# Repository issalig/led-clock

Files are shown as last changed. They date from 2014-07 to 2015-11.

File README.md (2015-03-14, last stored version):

led-clock
=========

Clock adventures with a led matrix.

After thinking about the simplest way to build a word clock I experimented with hand-soldered led matrices, 74HC595, 7219 and others to end up with the mighty 7219 and 8x8 led matrices.

7219 works with common cathode displays but a nice workaround to make it work with common anode matrices is to interchange rows by cols (transposing the matrix) and do the same (transposing it again) from software. Anyway, the PCB has been designed to support both c.c. and c.a. as well as 3mm matrices.

In order to make it richer, led-clock supports a humidity sensor and a pressure sensor. Additional sensors are also supported via I2C or SPI.

Hardware list
-------------

  - Arduino Pro Mini
  - Max7219
  - Led matrix 8x8 5mm/3mm common cathode or anode
  - Humidity sensor DHT11
  - Pressure sensor BMP180
  - 2 buttons

Board features
--------------

  - Small factor 5cmx5cm (fits in cheap PCB manufacturing)
  - Exported I2C, SPI and Analog pins
  - Stackable (1 or more matrices)
  - Support for common cathode and common anode

Software
--------

  Arduino has been chosen as the development environment due to the available libraries and its simplicity. MSP430 has been also considered but I was not able to make it work. Any volunteer?

  Operation modes:
  -Sleep. Wake up when button is touched
  -Alarm.

Clock layout
------------

  The idea is to have different interchangeable covers allowing the clock to easily change its appearance (and behaviour).
  By default two types of clock are designed:
  
- word clock
      Consists of a grid of characters that contain the words for telling the time in natural language.
      
- number/symbol clock
      Consists of a grid with digits and some extra symbols to indicate weather, moon, etc, ...
      
- calendar
	  Consists of a grid with days of week, month, weather, ... (mark first of month to calculate number of day)
	  
- anyclock
    Feel free to design your own clock, just represent your info in 64 elements (or more)

TODO
----
  - Checklist
	- 3.3v and 5v on board
		(boost for 5v even with batt)
		(3.3v with logic level or dedicated?)
		http://lowpowerlab.com/blog/2014/03/13/moteino-power-shield-now-available/
    - Lipo battery or 3xAAA???
	- Boost??
	- Jumper for A or K
	- datain for 5219 on not pwm??
	- 2 button
		1 is mode: sleep, set hour, 
		1 is set:  +1, next option
	- 3 button	
    - buzzer connection  //1M resistor ??? just servo/generic connector (-+S)
	- remote connection // risk, interference with voltage, just connector(-+S)
	- xronos clock (how they manage buttons, eeprom)
  - Wishlist

  - New PCB for 1st 1/4 2015 (SMD)
    - (OK) Correct GND mask from previous version 0.3
    - (OK) Remove DS1307 circuitry and substitute it for a module
	- (OK) Nokia screen
    - (OK) Correct button footprint holes
	- (OK) Documentation for pinout
	- (OK) Support for radio TEA5767
	- (OK) Possibility of adding capes
    - (OK) Pinout assignment and reserved pins
	- (OK) Pass also I2C, SPI pins on stackable horizontal	
	- (OK) Remote IR 1838
	
  - Software  
    - Grid data structure for symbols    
    - Grid editor (http://jsfiddle.net/AAg8e/4/)
    
  - Case
    - Carboard, bands and needles. Easy to change front mask cover
    - Wood. (Anyone with a laser cutter/CNC?)
 
 - Masks
	- word, temperature, humidex, calendar, spectrum analyzer
	- rotating wheel and servo?
 - Capes
	- stackable capes: nokia screen, communication, motor, radio TEA5767 / TDA7330 ...

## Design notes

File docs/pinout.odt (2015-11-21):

Pin | Function | Phys Posit | Board2 | Board 3 | Board 4 | Exp | Notes
A0 | | | B | | DataIn7219 | x
A1 | | | B | | IR1838!! | x | Battery?
A2 | | | B | | LDR | x
A3 | | | B | | DHT11 | x
A4 | SDA (I2C) | Variable | | Baro,RTC | Baro,RTC,TEA | x
A5 | SCL (I2C) | Variable | | Baro,RTC | Baro,RTC,TEA | x
A6 | | Variable | | NC | NC | | Button3?
A7 | | Variable | | NC | NC
D0 | RX | | | | | x | Comm
D1 | TX | | | | | x | Comm
D2 | | | | Button0 | Button0
D3 | PWM | | | Button1 | RGB/R | x | RGB/Servo0
D4 | | | | Button2 | Button1
D5 | PWM | | | Button3 | RGB/G | x | RGB/Servo1
D6 | PWM | | | DHT11 | RGB/B | x | RGB/Servo2
D7 | | | | load7219 | Load7219/ rstnokia-1/SD_CS
D8 | | | | clk7219 | Clk7219/ dcnokia-3/TFT_DC
D9 | PWM | | | dataIn7219 | dataIn7219/ lightnokia-7/TFT_RST | x | Change to Analog pin?
D10 | SS (SPI) PWM | | 7219 | | Cenokia-2/CS_TFT | x
D11 | MOSI (SPI) PWM | | 7219 | | DINNokia-4/TFT_SDA-SD_MOSI | x
D12 | MISO (SPI) | | 7219 | | SD_MISO | x
D13 | SCK (SPI) LED | | | | SCKNokia-5 / SD_SCK TFT_SCK | x

Quality control 0,4

rgb OK, queda azul ??? comparte con dht11 por D6

tft inverted!!!!

nokia, sin resistencias en sck sda, transistor mal patillaje, jumper para setear luz?

rtc

radio, no está ruteado a4SCL a5sda I2C !!!

ir

ldr

bmp ok

dht ok está en el 6 y debería ser 3, colapsa con RGB (B)

7219 Anode OK

check resistejcias nokia, funciona script

servos, mal pinout, colapsan con boton, soldar machos en placa

cambiar pinout antena a la derecha y dejar masa en medio LR

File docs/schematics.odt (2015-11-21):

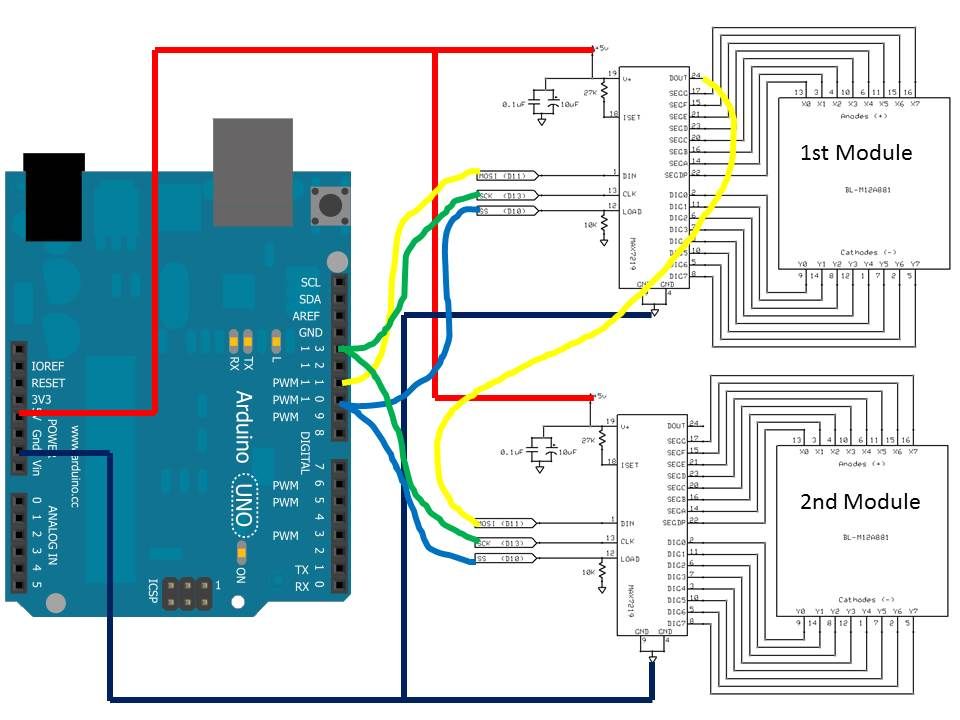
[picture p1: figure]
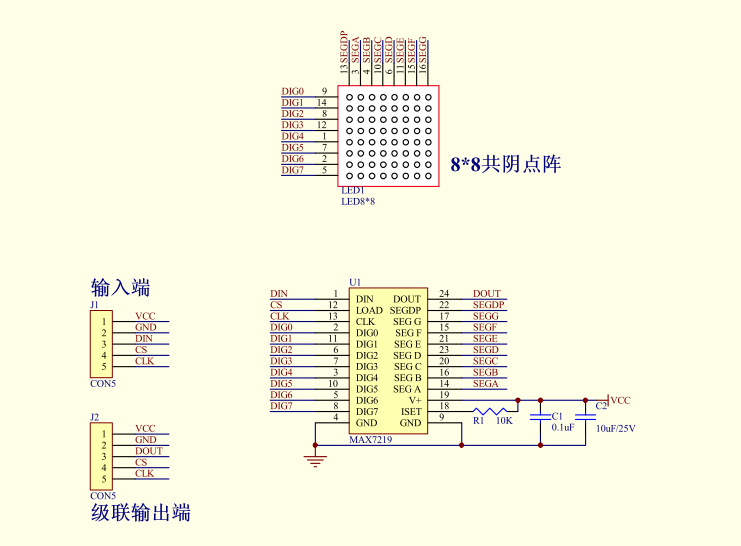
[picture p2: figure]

UVp-2088 Column Anode → Common cathode in row

Row Cathode

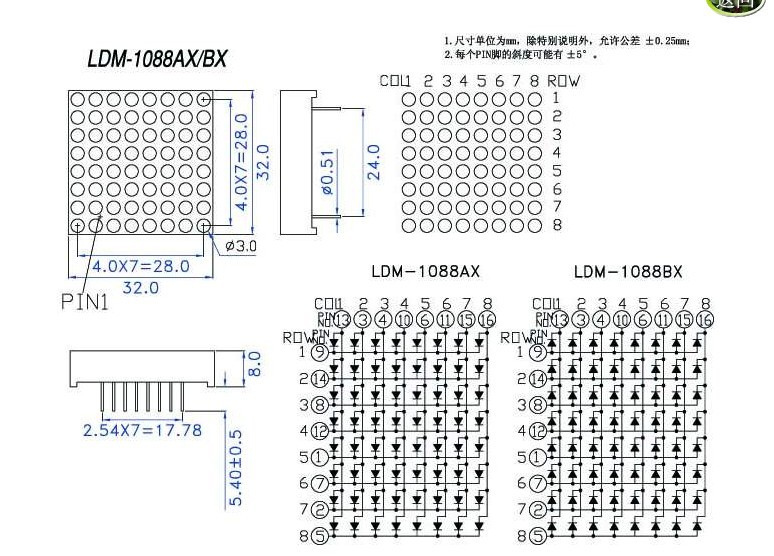
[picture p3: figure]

(http://i0.wp.com/tronixstuff.com/wp-content/uploads/2013/09/max7219_resistor_table.jpg)

(http://i0.wp.com/tronixstuff.com/wp-content/uploads/2013/09/max7219_resistor_table.jpg)

http://i0.wp.com/tronixstuff.com/wp-content/uploads/2013/09/max7219_resistor_table.jpg

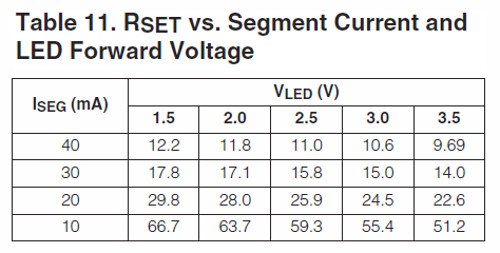
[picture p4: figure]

http://www.planetarduino.org/?cat=432

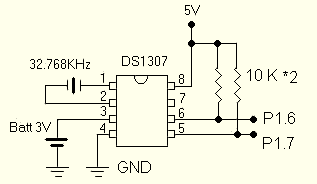
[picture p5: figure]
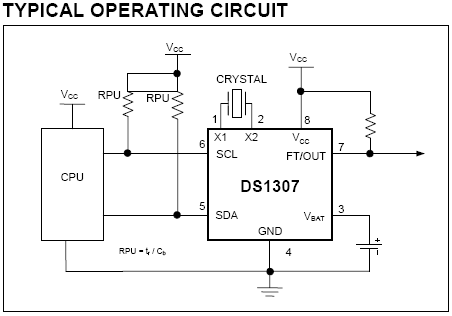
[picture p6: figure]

conect rtc to arduino.

conect SDA to Arduino A4.
conect SCL to Arduino A5.
conect vcc to +5v
conect gnd to gnd

http://www.instructables.com/id/Clock-with-termometer-using-Arduino-i2c-16x2-lcd-D/

http://www.sharatronica.com/cd4017.html

Sensor óptico

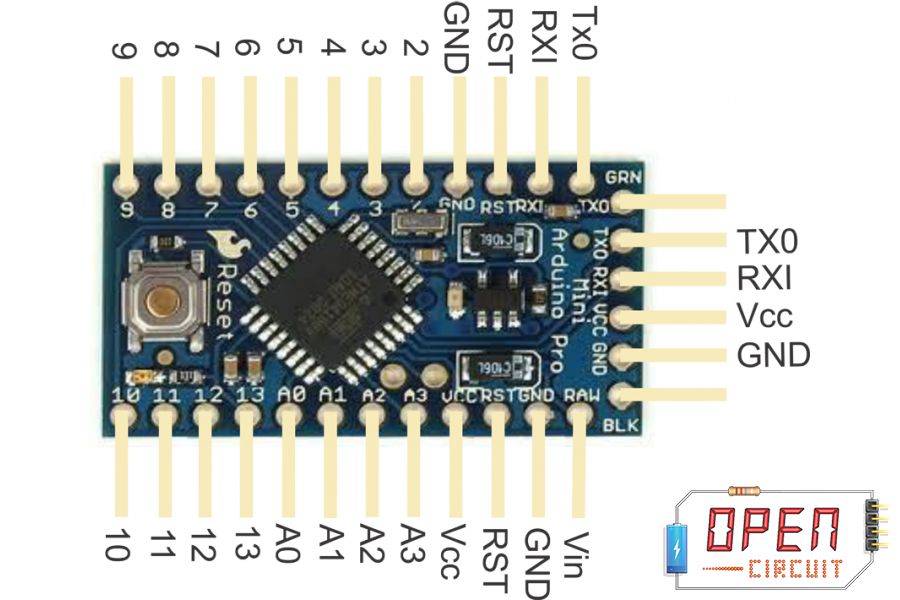
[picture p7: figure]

http://www.hobbytronics.co.uk/mosfet-voltage-level-converter

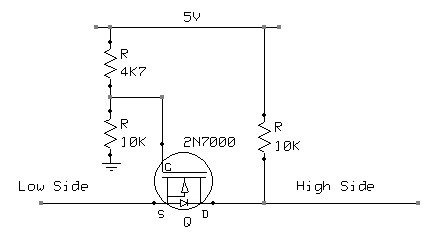
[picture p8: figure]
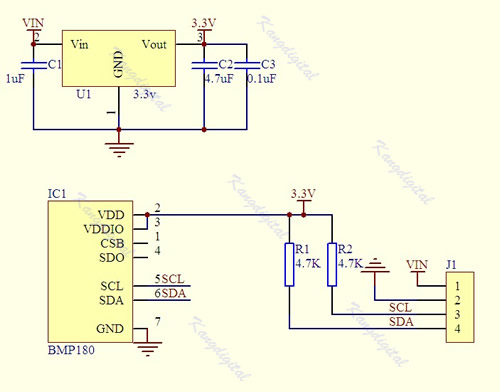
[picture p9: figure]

Placa

Main board

En v0.2 están A0, A1, A2, A3 para botones (en placa A0, A1, A2, A3)

El chip usa los pines 10, 11, 12

Se exportan 2-9 (en placa D2-D9)

13 libre

Botones → En v.0.1 K4 es A0, K3 es A1. http://arduino.cc/en/Tutorial/InputPullupSerial

pinMode(0, INPUT_PULLUP); analogRead(0); (se han cableado a analog)???

TODO

Arreglar conexión masas en V.0.3 para V.0.4. OK

Revisar agujeros batería, demasiado grandes. ELIMINAR

Revisar agujeros switch, demasiado pequeños. OK

Añadir TEA5767 / TDA7330 http://www.vwlowen.co.uk/arduino/bedside-clock/page2.htm

http://nicuflorica.blogspot.ro/2013/06/radio-fm-cu-tea5767-si-arduino-ii.html

http://blog.simtronyx.de/en/simple-fm-stereo-radio-with-a-tea5767-breakout-module-and-an-arduino/

http://nicuflorica.blogspot.ro/2014/11/modul-de-afisare-cu-8-cifre-led-din-7_11.html

Sensor-power

RTC se conecta por I2C SDA (A4) SCL (A5)

Scanning...

I2C device found at address 0x50 ! MEM

I2C device found at address 0x68 ! RTC

done

BMP180 SDA (A4) SCL (A5) (OK)

DHT11 conecta a D6 (OK)

BOOST (pendiente)

Es posible usar otros con SerialTWI

SPI: 10 (SS), 11 (MOSI), 12 (MISO), 13 (SCK).

Poner también batería?

Cargador? 2 AA

In addition, some pins have specialized functions:

- Serial: 0 (RX) and 1 (TX). Used to receive (RX) and transmit (TX) TTL serial data. These pins are connected to the TX-0 and RX-1 pins of the six pin header.
- External Interrupts: 2 and 3. These pins can be configured to trigger an interrupt on a low value, a rising or falling edge, or a change in value. See the attachInterrupt() (http://arduino.cc/en/Reference/AttachInterrupt) function for details.
- PWM: 3, 5, 6, 9, 10, and 11. Provide 8-bit PWM output with the analogWrite() (http://arduino.cc/en/Reference/AnalogWrite) function.
- SPI: 10 (SS), 11 (MOSI), 12 (MISO), 13 (SCK). These pins support SPI communication, which, although provided by the underlying hardware, is not currently included in the Arduino language.
- LED: 13. There is a built-in LED connected to digital pin 13. When the pin is HIGH value, the LED is on, when the pin is LOW, it's off.

The Pro Mini has 8 analog inputs, each of which provide 10 bits of resolution (i.e. 1024 different values). Four of them are on the headers on the edge of the board; two (inputs 4 and 5) on holes in the interior of the board. The analog inputs measure from ground to VCC. Additionally, some pins have specialized functionality:

- I²C: A4 (SDA) and A5 (SCL). Support I²C (TWI) communication using the Wire library (http://arduino.cc/en/Reference/Wire).

There is another pin on the board:

- Reset. Bring this line LOW to reset the microcontroller. Typically used to add a reset button to shields which block the one on the board.

# Protel Gerber Layer Names

GTO - Gerber Top Overlay (silkscreen)

GBO - Gerber Bottom Overlay (silkscreen)

GTL - Gerber Top Signal

GBL - Gerber Bottom Signal

GTS - Gerber Top Solder Mask

GBS - Gerber Bottom Solder Mask

GTP - Gerber Top Paste Mask

GBP - Gerber Bottom Paste Mask

GM1 - Gerber Mechanical 1

GM2 - Gerber Mechanical 2

GM3 - Gerber Mechanical 3

GM4 - Gerber Mechanical 4

GDD - Gerber Drill Drawing

GD1 - Gerber Drill Drawing, Top To Mid 1

GD2 - Gerber Drill Drawing, Mid 1 To Mid 2

GDG - Gerber Drill Guide

GG1 - Gerber Drill Guide, Top To Mid 1

GG2 - Gerber Drill Guide, Mid 1 To Mid 2

GPT - Gerber Top Pad Master

GPB - Gerber Bottom Pad Master

GKO - Gerber Keepout

PO1 - Gerber Panels

REP - Report file

TXT - ASCII NC Drill

DRL - EIA NC Drill

DRR - NC Drill Report

APR - Aperature File

Kicad, Plot, Drill . Kicad2itead.bat

2. Gerber files needed for 2-layer & 4-layer PCB boards:

Top layer: pcbname.GTL

Bottom layer: pcbname.GBL

Solder Stop Mask top: pcbname.GTS

Solder Stop Mask Bottom: pcbname.GBS

Silk Top: pcbname.GTO

Silk Bottom: pcbname.GBO

NC Drill: pcbname.TXT

Outline layer: pcbname.GKO or pcbname.DO

Note:

- All the gerber files must be in RS-274x format, except the drill file should be in Excellon format.
- If there is no pcbname.GKO or DO file, please make sure the PCB outline or shape shall at least be specified in other layer, silkscreen or soldermask layer etc.
- If soldermask layers are not required, please clarify surface finish for both sides when you submit your gerber files.

Coin cell holder

http://www.shogyo.com/pdf/ch224-2032lf.pdf

NOKIA LCD takes 4 digital lines

3.3V !!!

http://www.google.es/url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,d.d24&psig=AFQjCNFrW_TDc2UuTrOCLbg6gxJRcV6MJQ&ust=1420762184205945

http://drianoxaman.blogspot.com.es/2013/03/arduino-usb-lipo-charger-5v-booster.html

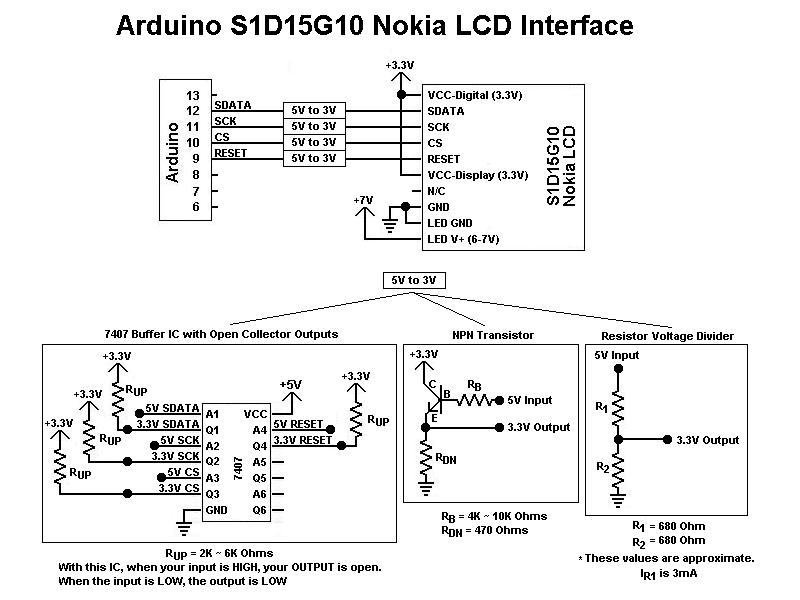
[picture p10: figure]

If you power display from 5 V, you should use 10K resistors on all pins, but either way with 5 V there could be problems with displaying and it will reduce it's life time.

There is 2 types of pinouts:

(https://dlnmh9ip6v2uc.cloudfront.net/assets/6/c/f/8/b/524dc9ea757b7f616e8b4569.png) (http://2.bp.blogspot.com/-_O3t61ENYds/U9dzQ2MU5WI/AAAAAAAAEZg/_emXqN5HmZw/s1600/IMG_20140729_130904411.jpg)

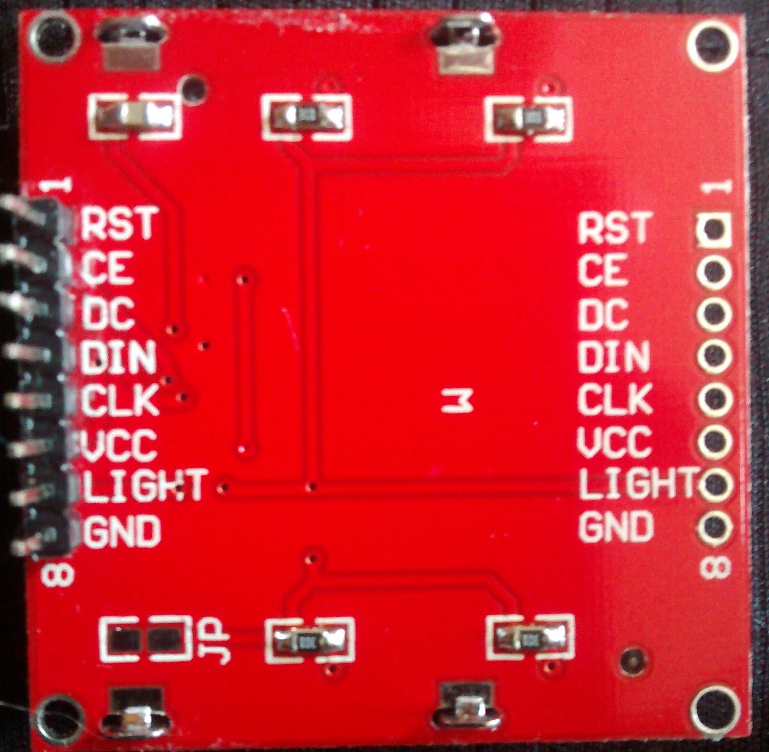
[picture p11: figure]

Pin number | Designator | Function | Notes
1 | VCC | power supply
2 | GND | ground
3 - 2 | SCE (CE) | chip select | usually grounded
4 - 1 | RST | RESET | Active with log. 0
5 - 3 | D/C (DC) | choose operating mode | Commands log. 0 Data log. 1
6 - 4 | DN (DIN) | Data | 1 byte of data
7 - 5 | SCLK (CLK) | Serial clock, synchronization
8 | LED (LIGHT) | Backlight | 3.3V

Posible ejemplo http://nicuflorica.blogspot.com.es/2013/06/afisajul-folosit-la-telefoanele-nokia_17.html

Resistencias para dimming 330 o Dim con D9, quitar uno

SDA SCK no van bien con la resistencia de 10k

http://forum.arduino.cc/index.php?topic=189741.0

!!!Se usa este pinout

1 | RST | Reset | Entrada
2 | CE | Chip Selection (Selección de chip) | Entrada
3 | DC | Data/Commands choice | Entrada
4 | DIN | Serial data in (D11) | Entrada
5 | CLK | Serial clock (D13) | Entrada
6 | VCC | Positive power supply (Alimentación positiva) | Entrada | 2.7V a 3.3V
7 | LIGHT | LED backlight supply | Entrada | Conectar a GND para max brillo
8 | GND | Ground (Tierra) | Entrada

#### Connections

RST – Reset
Connect this to any digital pin of Arduino or connect it permanently to high using a 10k ohm resistor if you do not care about the remote reset capability. To reset the screen automatically connect this pin to the Arduino reset. Does not require 10kΩ resistor for level shifting.

CE – Chip Select
Connect this to any digital pin of Arduino with a 1kΩ resistor in between. By connecting this pin to GND you can not reuse the LCD’s pins between screen updates and should be done only when no other SPI devices are being used.

DC – Mode Selection
Connect this to any digital pin of Arduino. Does not require 10kΩ resistor for level shifting.

DIN – Serial Data In (MOSI)
Connect this to Arduino pin 11. Does not require 10kΩ resistor for level shifting.

CLK – Serial Clock Line
Connect this to Arduino pin 13. Does not require 10kΩ resistor for level shifting.

VCC – Power input
Connect this pin to 3.3V pin of Arduino. Connecting it to 5V may decrease the LCD’s life.

BL – Back Light LED
Connect this pin to any PWM pin of Arduino with a 330Ω resistor in between to dim the back light as you please. You can also connect it to 3.3V.

GND – Ground
Connect this to the Arduino GND pin.

Connecting SCLK and DN(MOSI) to Arduino’s hardware SPI pins helps to achieve a faster data transfer. These pins do not require the resistors mentioned above but are mentioned here for the purpose of extra protection.

#### Images

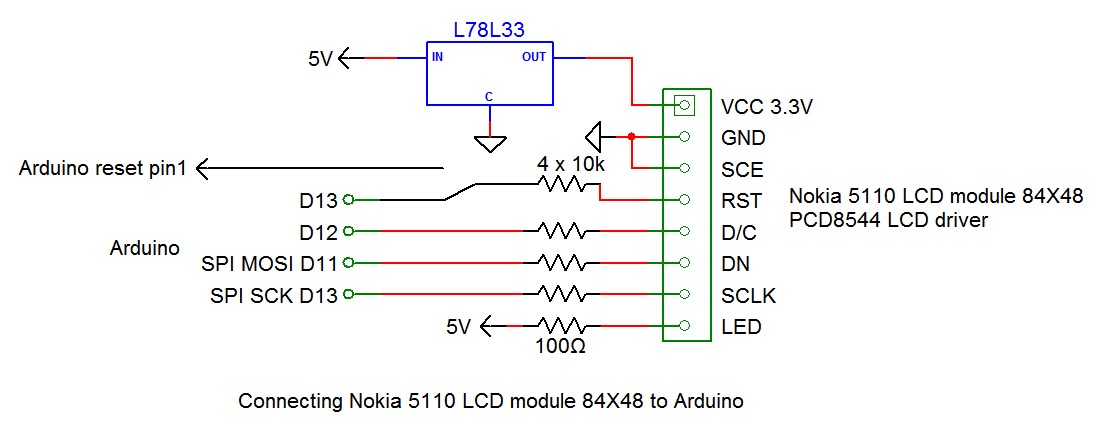
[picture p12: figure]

http://www.hobby-hour.com/electronics/resistorcalculator.php

https://learn.sparkfun.com/tutorials/graphic-lcd-hookup-guide

pinout alternativo http://electronicavm.net/2012/02/13/nokia-lcd-3310-arduino/comment-page-1/

LCD Pin | Arduino Pin | Notes
1 - VCC | 3.3V (VCC) | 3.3V only (not 5V!)
2 - GND | GND
3 - SCE | 7 | Can be any digital pin.
4 - RST | 6 | Can be any digital pin.
5 - D/C | 5 | Can be any digital pin.
6 - DN(MOSI) | 11 | Can't be moved.
SCLK | 13 | Can't be moved.
LED | 9 | Can be any PWM pin. 330Ω resistor in between the pins.

// Software SPI (slower updates, more flexible pin options):

// pin 7 - Serial clock out (SCLK)

// pin 6 - Serial data out (DIN)

// pin 5 - Data/Command select (D/C)

// pin 4 - LCD chip select (CS)

// pin 3 - LCD reset (RST)

Adafruit_PCD8544 display = Adafruit_PCD8544(7, 6, 5, 4, 3);

// Hardware SPI (faster, but must use certain hardware pins):

// SCK is LCD serial clock (SCLK) - this is pin 13 on Arduino Uno

// MOSI is LCD DIN - this is pin 11 on an Arduino Uno

// pin 5 - Data/Command select (D/C)

// pin 4 - LCD chip select (CS)

// pin 3 - LCD reset (RST)

// Adafruit_PCD8544 display = Adafruit_PCD8544(5, 4, 3);

// Note with hardware SPI MISO and SS pins aren't used but will still be read

// and written to during SPI transfer. Be careful sharing these pins!

pcdtestisma

Adafruit_PCD8544 display = Adafruit_PCD8544(8, 10, 7);

Transistor para backlight. Ejemplo

http://andybrown.me.uk/2010/11/28/lcd-backlight-and-contrast-manager/

RTC.

Not very accurate.

The two Sainsmart Tiny-RTC units I just received had CR2032 (non-rechargeable) lithium coin cells in them. THESE ARE NOT THE RIGHT BATTERY TYPE for Tiny-RTC circuits, and may leak or catch fire if the circuit is left powered from Vcc for long periods of time!

You *can* use the CR2032 battery and it should last 3 years or more in this application, but the Tiny-RTC module must have its battery charging circuit removed to do so safely. The modification is: Remove R5, D1, R4, R6, and replace R6 with a shorting wire. Or you can try to find the proper battery, which is a LIR2032 and can be ordered easily right here on Amazon but probably isn't available at your neighborhood Radio Shack.

Three stars because the circuits themselves work just fine, -2 for shady supplier putting cheap, incorrect batteries in.

If you need to reset the date and time look here http://forum.arduino.cc/index.php?topic=184908.0

the addresses are
x50 EEPROM
x68 RTC

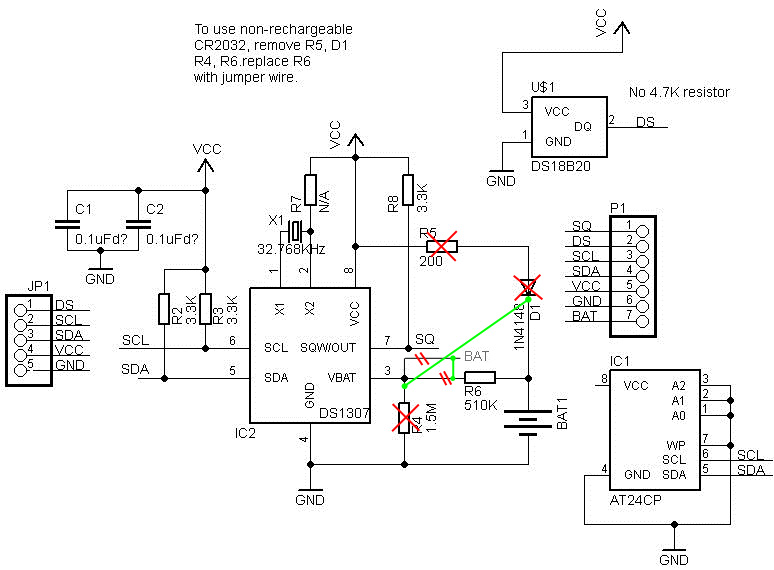
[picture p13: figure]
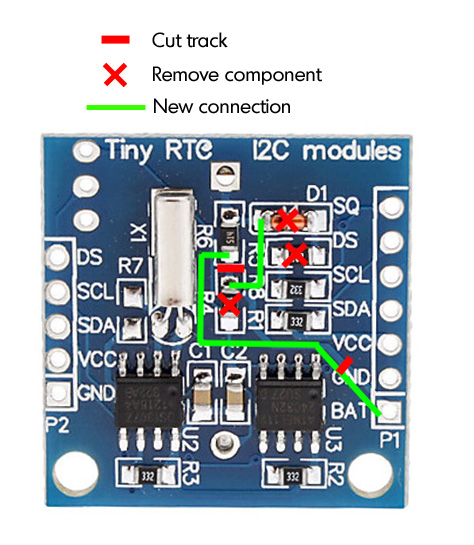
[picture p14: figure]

http://electronics.stackexchange.com/search?q=url%3Ahttp%3A%2F%2Farduino.stackexchange.comYou can always use the analog pins for digital writing.

digitalRead() works on all pins. It will just round the analog value received and present it to you. If analogRead(A0) is greater than or equal to 512, digitalRead(A0) will be 1, else 0.

digitalWrite() works on all pins, with allowed parameter 0 or 1. digitalWrite(A0,0) is the same as analogWrite(A0,0), and digitalWrite(A0,1) is the same as analogWrite(A0,255)

analogRead() works only on analog pins. It can take any value between 0 and 1023.

analogWrite() works on all analog pins and all digital PWM pins. You can supply it any value between 0 and 255.

The analog pins let you read/write analog values - basically, instead of giving out a voltage of 0 or 5 (as with digital), they can give a range of voltages between 0 and 5 (both as input and output). Note that the voltage during analog output is only the observed voltage with a multimeter. In reality, the analog pins send pulses of 0V and 5V signals to get an output that "looks" analog (this is PWM).

Regarding the number of pins: keep in mind that the PWM pins can be used for analog output. If you run out of pins, you can use multiplexing to make more. It is not necessary to get another Arduino.

LED RGB Common cathode

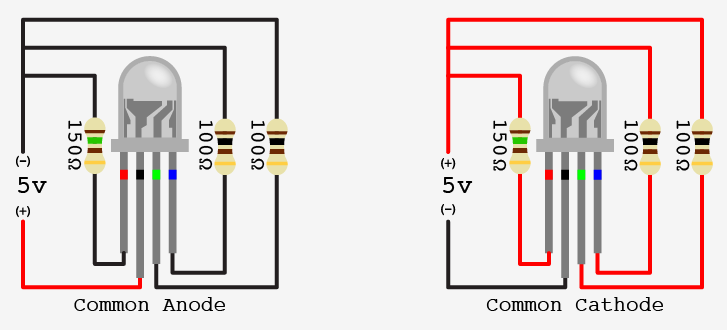
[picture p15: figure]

200mA is the maximum of all the combined pins, no one pin to exceed 40mA

3x 20mA → 60

without transistor

Max current 20mA, working at 10mA

RGB 160, 150, 1

http://talkingelectronics.com/projects/30%20LED%20Projects/30%20LED%20Projects.html

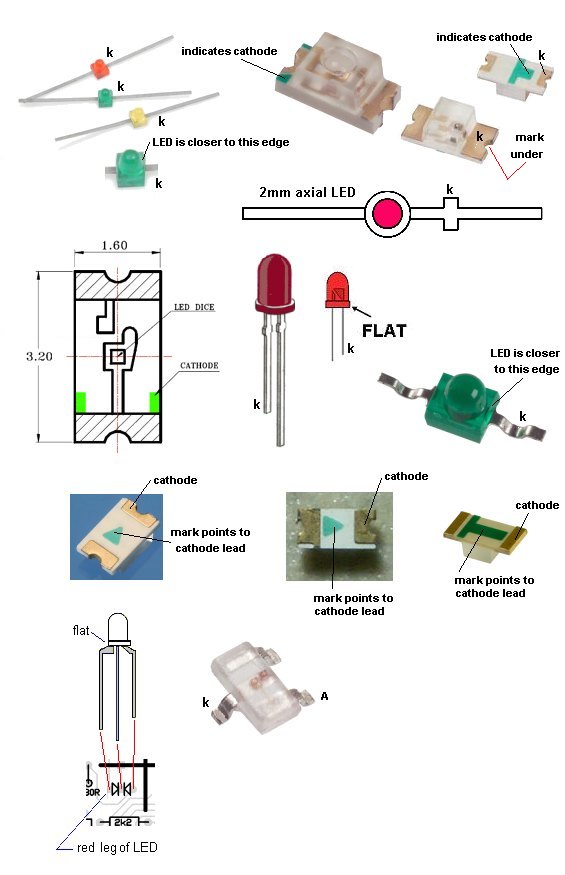
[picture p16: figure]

Night clock

http://www.instructables.com/id/LED-Dawn-Sunrise-Alarm-Clock-Nightlight-Secur/all/?lang=es

Level shifter

http://husstechlabs.com/support/tutorials/bi-directional-level-shifter/

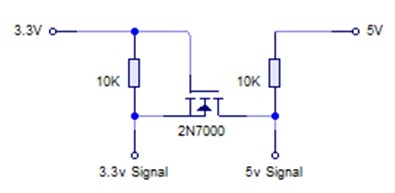
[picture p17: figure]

Level shifter

I used the general purpose 2N7000 MOSFET, but I had used some 3A power MOSFET’s while I was waiting for the 2N7000’s to arrive! Note that the Gate is always connected to the LOWER voltage.

http://www.hobbytronics.co.uk/mosfet-voltage-level-converter

Pegar un vistazo a esto

http://www.thefrankes.com/wp/index.php?cat=41&paged=7

https://learn.sparkfun.com/tutorials/using-the-logic-level-converter

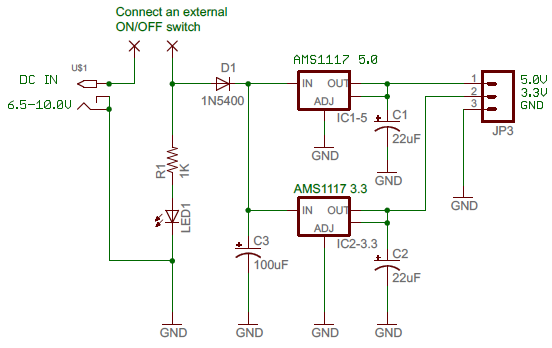
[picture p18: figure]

http://arduino-info.wikispaces.com/IR-RemoteControl

1.- Digital (PWM?) 2.- GND 3 VCC

http://arduino-info.wikispaces.com/file/view/IR-Receiver-AX-1838HS.pdf

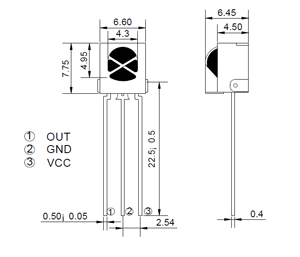
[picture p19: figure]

http://drianoxaman.blogspot.com.es/2013/03/arduino-usb-lipo-charger-5v-booster.html

https://medium.com/@tomsimon/lipo-charger-board-for-the-arduino-nano-39e709f459bc

https://www.tindie.com/products/onehorse/lipo-battery-charger-add-on-for-teensy-31/

TEA5767

http://blog.simtronyx.de/en/simple-fm-stereo-radio-with-a-tea5767-breakout-module-and-an-arduino/

http://www.vwlowen.co.uk/arduino/bedside-clock/bedside-clock.htm

https://www.electronicsblog.net/arduino-fm-receiver-with-tea5767/

Light encoding, no suele ir muy bien.

http://www.wayneandlayne.com/projects/blinky/design/

https://github.com/mossblaser/Clockie

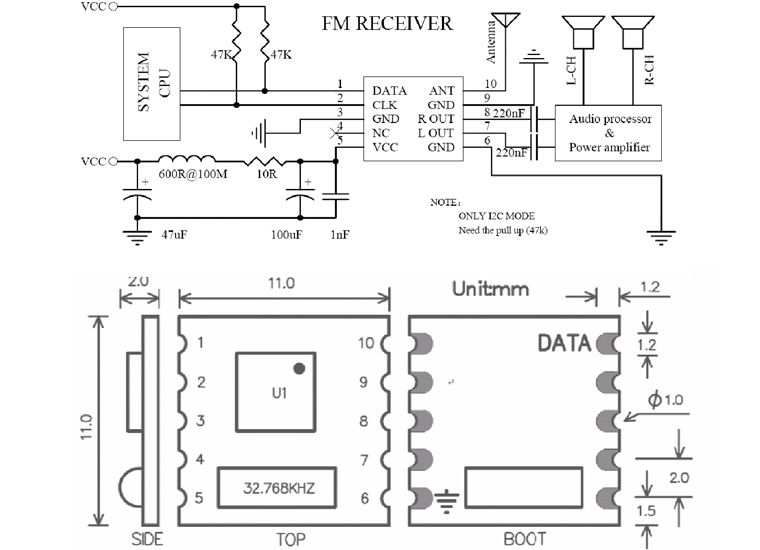
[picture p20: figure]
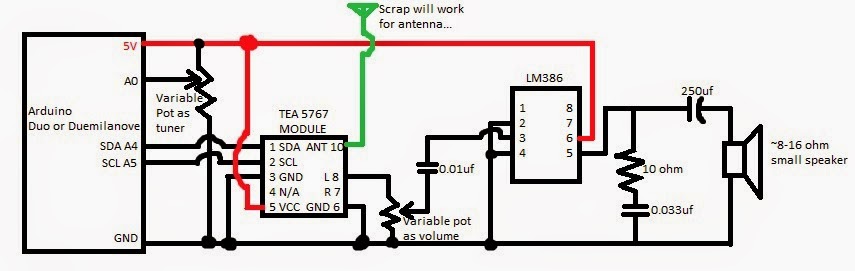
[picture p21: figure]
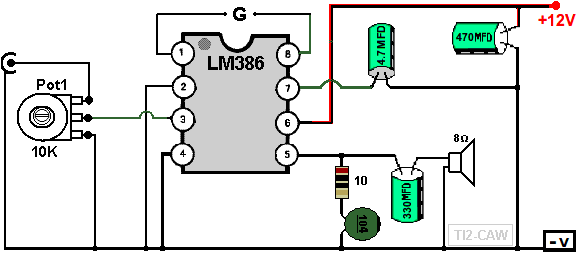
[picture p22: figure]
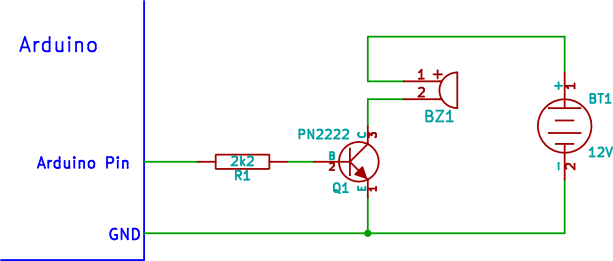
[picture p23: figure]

2n2222 OK, con 5v ok !!!

piezo al pin arduino 1Mohm, se oye suficiente para beep

http://hackaweek.com/hacks/?p=327

http://xronosclock.com/files/xronos_2.1_schematic.png

USB MICRO

https://www.sparkfun.com/datasheets/Prototyping/Micro-USB.pdf

http://portal.fciconnect.com/Comergent//fci/drawing/10118192.pdf

Shield y GND

http://pinouts.ru/Slots/usb_pinout.shtml

http://electronics.stackexchange.com/questions/4515/how-to-connect-usb-connector-shield

1.8 SPI TFT

Arduino (Mini, Nano, Uno) | HY-1.8 SPI with SD adapter
D7 | Pin 14 (SD CS)
*D8 | Pin 07 (A0)
*D10 (SS) | Pin 10 (CS)
*D11 (MOSI) | Pin 08 (SDA), Pin 13 (SD MOSI)
*D12 (MISO) | Pin 12 (SD MISO)
*D13 (SCK) | Pin 09 (SCK), Pin 11 (SD SCK)
*D9 | Pin 06 (RESET)
5V (VCC) | Pin 02 (VCC)
GND | Pin 01 (GND)
5V (VCC) | Pin 15 (LED+)
GND | Pin 16 (LED-)

graphictest.c

#define TFT_CS 10

#define TFT_RST 9 // you can also connect this to the Arduino reset

// in which case, set this #define pin to 0!

#define TFT_DC 8

http://blog.simtronyx.de/en/an-image-slideshow-with-an-arduino-and-a-tft-display-with-a-sd-card-module/

sketchmarch17a

#include <Adafruit_GFX.h> // Core graphics library

#include <Adafruit_ST7735.h> // Hardware-specific library

#include <SPI.h>

#include <SD.h>

#define SD_CS 7 // Chip select line for SD card

#define TFT_CS 10 // Chip select line for TFT display

#define TFT_DC 8//9 // Data/command line for TFT

#define TFT_RST 9//8 // Reset line for TFT (or connect to +5V)

Adafruit_ST7735 tft = Adafruit_ST7735(TFT_CS, TFT_DC, TFT_RST);

void setup(void) {

Serial.begin(9600);

tft.initR(INITR_BLACKTAB); // initialize a ST7735S chip, black tab

Serial.print("Initializing SD card...");

if (!SD.begin(SD_CS)) {

Serial.println("failed!");

return;

}

Serial.println("OK!");

}

void loop() {

File dir=SD.open("/");

dir.rewindDirectory();

while(true) {

File entry = dir.openNextFile();

if (! entry) {

// no more files

//Serial.println("**nomorefiles**");

break;

}

// Print the 8.3 name

Serial.print(entry.name());

// Recurse for directories, otherwise print the file size

if (entry.isDirectory()) {

Serial.println("/");

}

else{

// files have sizes, directories do not

Serial.print("\t\t");

Serial.println(entry.size(), DEC);

if(bmpDraw(entry.name(),0,0))delay(5000);

}

entry.close();

}

/*

bmpDraw("image_1.bmp", 0, 0);

delay(5000);

bmpDraw("image_2.bmp", 0, 0);

delay(5000);

bmpDraw("image_3.bmp", 0, 0);

delay(5000);

*/

}

// This function opens a Windows Bitmap (BMP) file and

// displays it at the given coordinates. It's sped up

// by reading many pixels worth of data at a time

// (rather than pixel by pixel). Increasing the buffer

// size takes more of the Arduino's precious RAM but

// makes loading a little faster. 20 pixels seems a

// good balance.

#define BUFFPIXEL 20

boolean bmpDraw(char *filename, uint8_t x, uint8_t y) {

File bmpFile;

int bmpWidth, bmpHeight; // W+H in pixels

uint8_t bmpDepth; // Bit depth (currently must be 24)

uint32_t bmpImageoffset; // Start of image data in file

uint32_t rowSize; // Not always = bmpWidth; may have padding

uint8_t sdbuffer[3*BUFFPIXEL]; // pixel buffer (R+G+B per pixel)

uint8_t buffidx = sizeof(sdbuffer); // Current position in sdbuffer

boolean goodBmp = false; // Set to true on valid header parse

boolean flip = true; // BMP is stored bottom-to-top

int w, h, row, col;

uint8_t r, g, b;

uint32_t pos = 0, startTime = millis();

if((x >= tft.width()) || (y >= tft.height())) return false;

Serial.println();

Serial.print("Loading image '");

Serial.print(filename);

Serial.println('\'');

// Open requested file on SD card

if ((bmpFile = SD.open(filename)) == NULL) {

Serial.print("File not found");

return false;

}

// Parse BMP header

if(read16(bmpFile) == 0x4D42) { // BMP signature

Serial.print("File size: "); Serial.println(read32(bmpFile));

(void)read32(bmpFile); // Read & ignore creator bytes

bmpImageoffset = read32(bmpFile); // Start of image data

Serial.print("Image Offset: "); Serial.println(bmpImageoffset, DEC);

// Read DIB header

Serial.print("Header size: "); Serial.println(read32(bmpFile));

bmpWidth = read32(bmpFile);

bmpHeight = read32(bmpFile);

if(read16(bmpFile) == 1) { // # planes -- must be '1'

bmpDepth = read16(bmpFile); // bits per pixel

Serial.print("Bit Depth: "); Serial.println(bmpDepth);

if((bmpDepth == 24) && (read32(bmpFile) == 0)) { // 0 = uncompressed

goodBmp = true; // Supported BMP format -- proceed!

Serial.print("Image size: ");

Serial.print(bmpWidth);

Serial.print('x');

Serial.println(bmpHeight);

// BMP rows are padded (if needed) to 4-byte boundary

rowSize = (bmpWidth * 3 + 3) & ~3;

// If bmpHeight is negative, image is in top-down order.

// This is not canon but has been observed in the wild.

if(bmpHeight < 0) {

bmpHeight = -bmpHeight;

flip = false;

}

// Crop area to be loaded

w = bmpWidth;

h = bmpHeight;

if((x+w-1) >= tft.width()) w = tft.width() - x;

if((y+h-1) >= tft.height()) h = tft.height() - y;

// Set TFT address window to clipped image bounds

tft.setAddrWindow(x, y, x+w-1, y+h-1);

for (row=0; row<h; row++) { // For each scanline...

// Seek to start of scan line. It might seem labor-

// intensive to be doing this on every line, but this

// method covers a lot of gritty details like cropping

// and scanline padding. Also, the seek only takes

// place if the file position actually needs to change

// (avoids a lot of cluster math in SD library).

if(flip) // Bitmap is stored bottom-to-top order (normal BMP)

pos = bmpImageoffset + (bmpHeight - 1 - row) * rowSize;

else // Bitmap is stored top-to-bottom

pos = bmpImageoffset + row * rowSize;

if(bmpFile.position() != pos) { // Need seek?

bmpFile.seek(pos);

buffidx = sizeof(sdbuffer); // Force buffer reload

}

for (col=0; col<w; col++) { // For each pixel...

// Time to read more pixel data?

if (buffidx >= sizeof(sdbuffer)) { // Indeed

bmpFile.read(sdbuffer, sizeof(sdbuffer));

buffidx = 0; // Set index to beginning

}

// Convert pixel from BMP to TFT format, push to display

b = sdbuffer[buffidx++];

g = sdbuffer[buffidx++];

r = sdbuffer[buffidx++];

tft.pushColor(tft.Color565(r,g,b));

} // end pixel

} // end scanline

Serial.print("Loaded in ");

Serial.print(millis() - startTime);

Serial.println(" ms");

} // end goodBmp

}

}

bmpFile.close();

if(!goodBmp)Serial.println("BMP format not recognized.");

return goodBmp;

}

// These read 16- and 32-bit types from the SD card file.

// BMP data is stored little-endian, Arduino is little-endian too.

// May need to reverse subscript order if porting elsewhere.

uint16_t read16(File f) {

uint16_t result;

((uint8_t *)&result)[0] = f.read(); // LSB

((uint8_t *)&result)[1] = f.read(); // MSB

return result;

}

uint32_t read32(File f) {

uint32_t result;

((uint8_t *)&result)[0] = f.read(); // LSB

((uint8_t *)&result)[1] = f.read();

((uint8_t *)&result)[2] = f.read();

((uint8_t *)&result)[3] = f.read(); // MSB

return result;

}

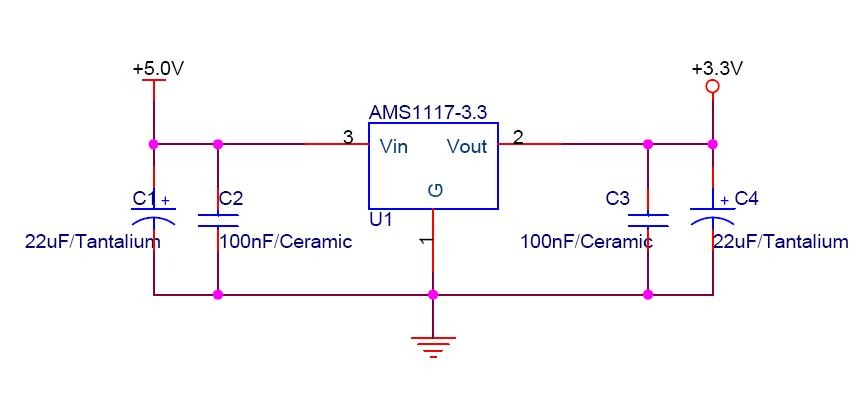
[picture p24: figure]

http://karve.in/?p=1583&page=5

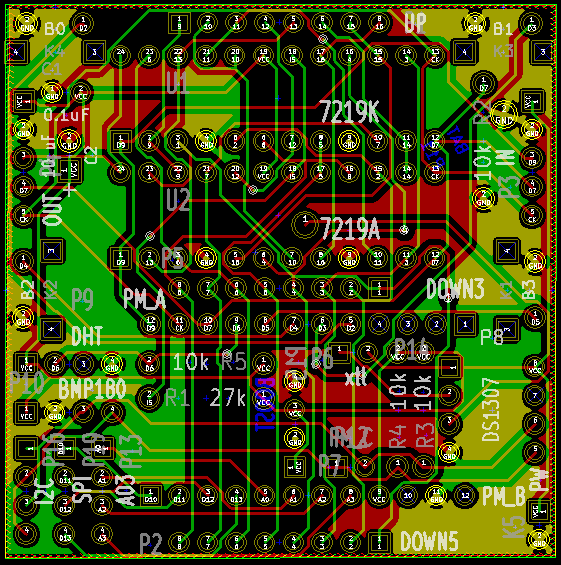
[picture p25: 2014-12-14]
hardware/matrix7219 - 0.3/itead-0.3/matrix7219.png

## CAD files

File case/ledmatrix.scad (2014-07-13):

//ledmatrix frame
//author: Ismael Salvador
//date: 13/07/2014

led_qty=1;
led_size=60.20;
led_height=60.20;
led_width=led_height*led_qty;
led_depth=9.20;

frame_thick=3;
frame_depth=led_depth+frame_thick*2;
frame_size=led_size + frame_thick;
frame_width=led_width + frame_thick;
frame_height=led_height + frame_thick;

screen_margin=0.2;

angle=15;

difference(){

//outer cube
cube([frame_height, frame_width, frame_depth], center=true);

//inner cube

translate([0,0,frame_thick])
cube([led_height, led_width, frame_depth*1.1], center=true);


//screen hole
//little bit smaller than inner
translate([0,0,-frame_thick])
cube([led_height-screen_margin, led_width-screen_margin, frame_depth*1.1], center=true);

}

stand_depth=frame_depth+6;
stand_height=sin(angle)*stand_depth;

//standoff front
translate([frame_size/2 + stand_height/2, 0, -frame_depth/2 + frame_thick/2 ])
cube([stand_height, frame_width, frame_thick], center=true);

//standoff base
translate([frame_height/2  - 1/2*frame_thick, -frame_width/2, -frame_depth/2])
cube([frame_thick, frame_width, stand_depth], center=false);
//bevel



//translate([0,0,15])
//cube([50,20,2], center=true)
//
//difference(){
//translate([0,20,15])
//cube([30,20,2], center=true);
//
//translate([-10,25,15])
//#cylinder(h = 5, r1 = 1, $fs = 0.1, center = true);
//
//translate([10,25,15])
//#cylinder(h = 5, r1 = 1, $fs = 0.1, center = true);


//}

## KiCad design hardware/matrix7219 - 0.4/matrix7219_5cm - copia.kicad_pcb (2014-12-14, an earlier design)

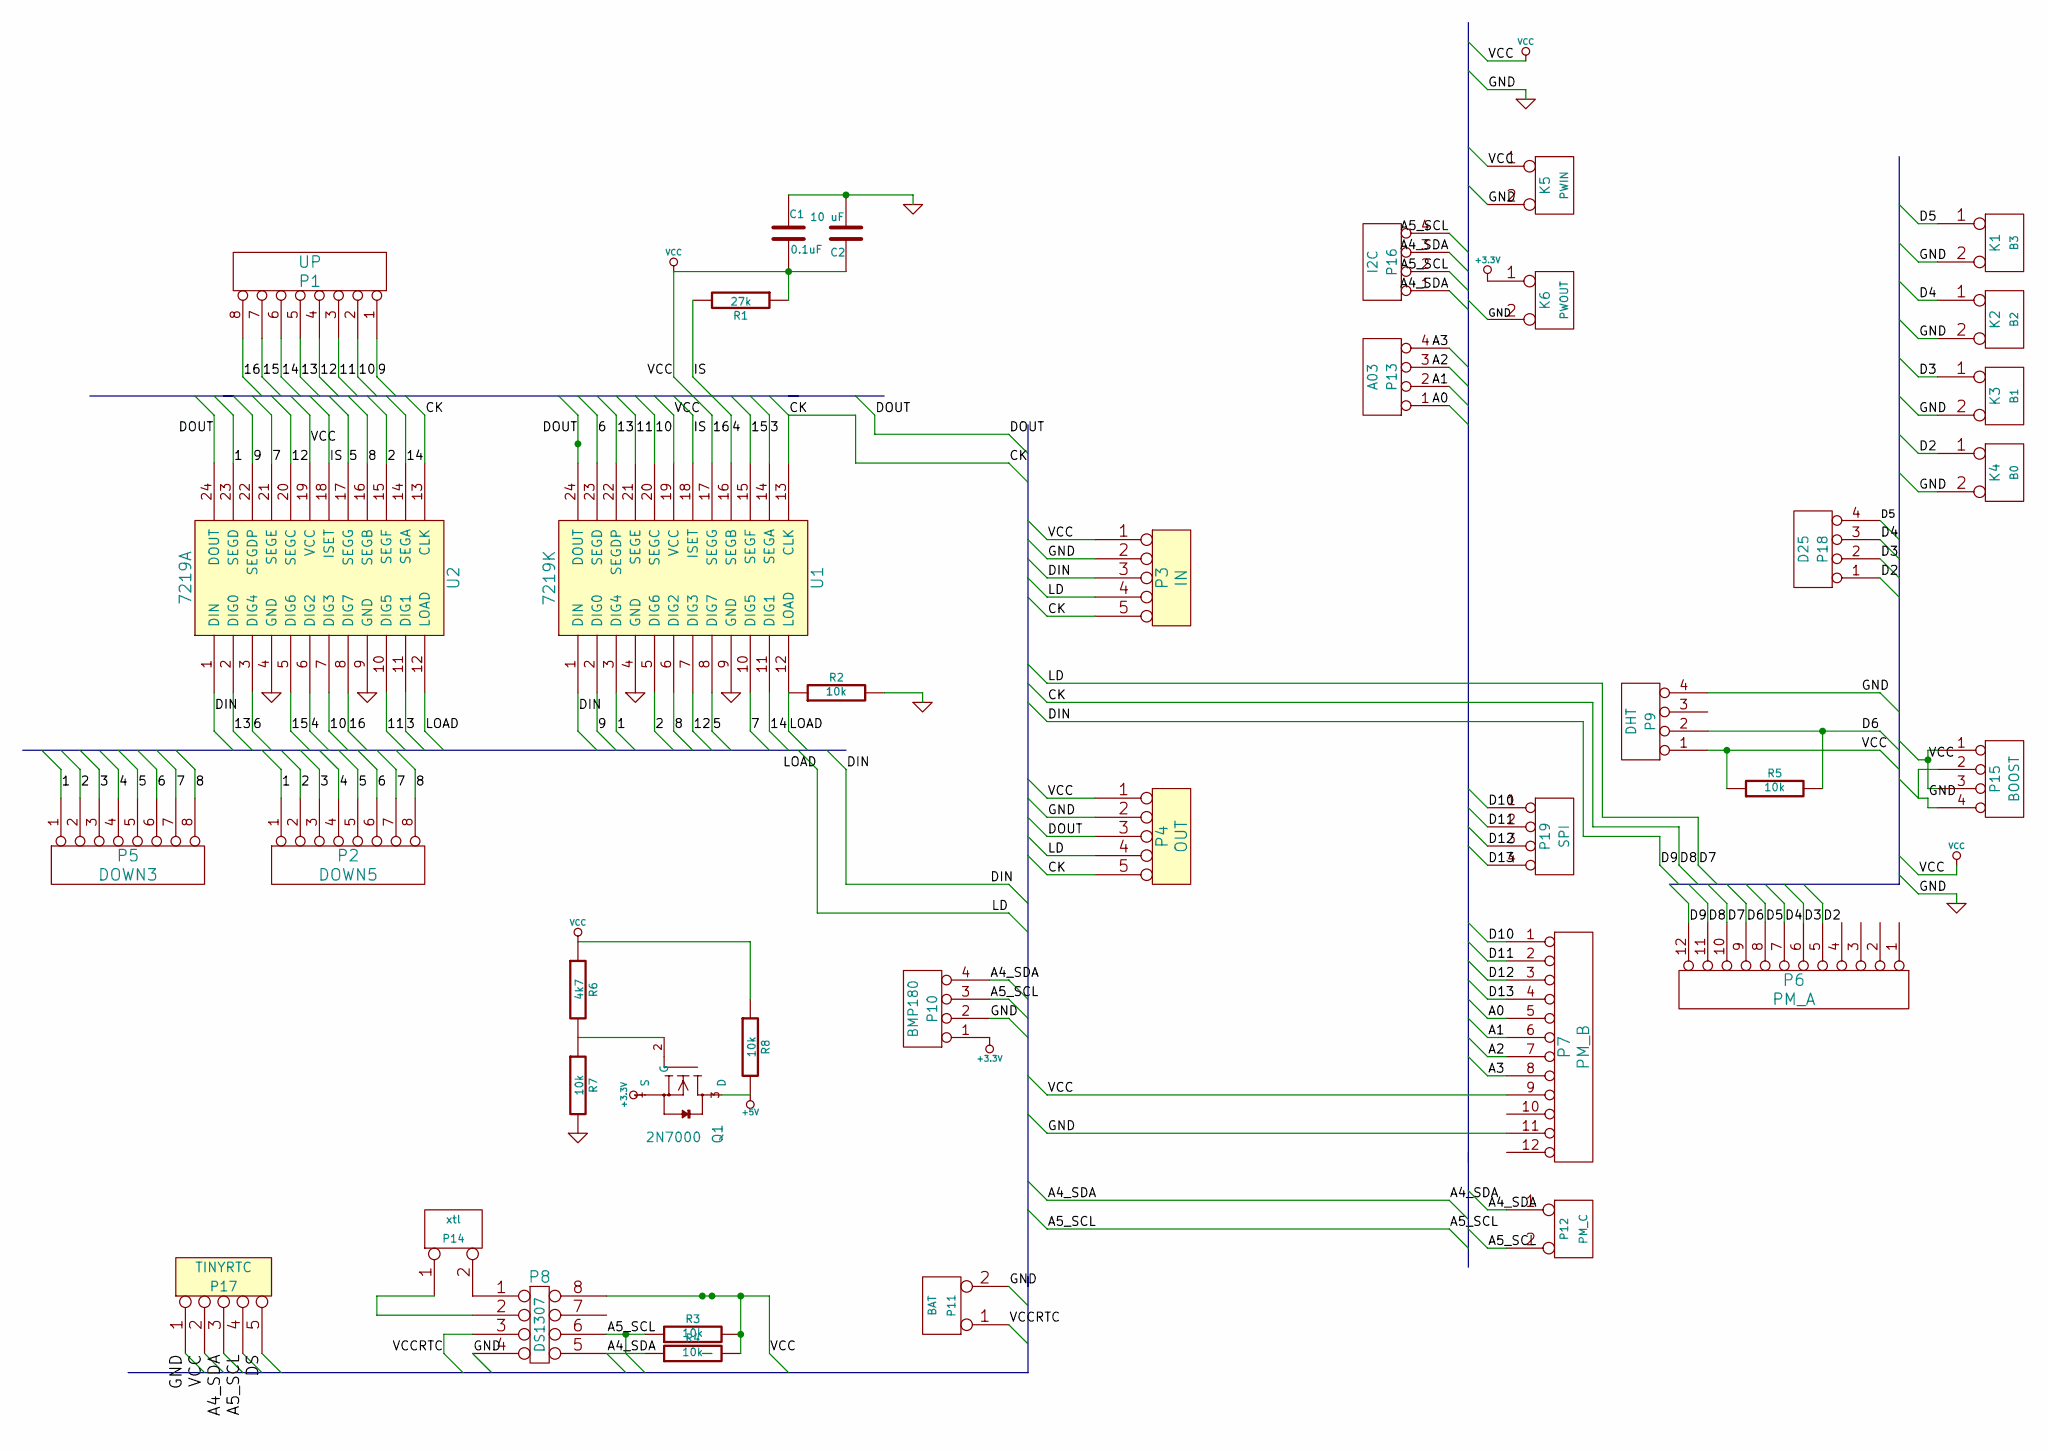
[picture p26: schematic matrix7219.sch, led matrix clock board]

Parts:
C1: 0.1uF
C2: 10 uF
K1: B3
K2: B2
K3: B1
K4: B0
K5: PWIN
K6: PWOUT
P1: UP
P2: DOWN5
P3: IN
P4: OUT
P5: DOWN3
P6: PM_A
P7: PM_B
P8: DS1307
P9: DHT
P10: BMP180
P11: BAT
P12: PM_C
P13: A03
P14: xtl
P15: BOOST
P16: I2C
P17: TINYRTC
P18: D25
P19: SPI
Q1: 2N7000; m-pad-2.1-TO92
R1: 27k
R2, R3, R4, R5, R7, R8: 10k
R6: 4k7
U1: 7219K
U2: 7219A

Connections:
+3.3V: K6.1, P10.1, Q1.1 (S)
+5V: Q1.3 (D), R8.2
/1: P2.1, P5.1, U1.3 (DIG4), U2.23 (SEGD)
/2: P2.2, P5.2, U1.5 (DIG6), U2.15 (SEGF)
/3: P2.3, P5.3, U1.14 (SEGA), U2.11 (DIG1)
/4: P2.4, P5.4, U1.16 (SEGB), U2.6 (DIG2)
/5: P2.5, P5.5, U1.8 (DIG7), U2.17 (SEGG)
/6: P2.6, P5.6, U1.23 (SEGD), U2.3 (DIG4)
/7: P2.7, P5.7, U1.10 (DIG5), U2.21 (SEGE)
/8: P2.8, P5.8, U1.6 (DIG2), U2.16 (SEGB)
/9: P1.1, U1.2 (DIG0), U2.22 (SEGDP)
/10: P1.2, U1.20 (SEGC), U2.7 (DIG3)
/11: P1.3, U1.21 (SEGE), U2.10 (DIG5)
/12: P1.4, U1.7 (DIG3), U2.20 (SEGC)
/13: P1.5, U1.22 (SEGDP), U2.2 (DIG0)
/14: P1.6, U1.11 (DIG1), U2.14 (SEGA)
/15: P1.7, U1.15 (SEGF), U2.5 (DIG6)
/16: P1.8, U1.17 (SEGG), U2.8 (DIG7)
/A0: P7.5, P13.1
/A1: P7.6, P13.2
/A2: P7.7, P13.3
/A3: P7.8, P13.4
/A4_SDA: P8.5, P10.4, P12.1, P16.1, P16.3, P17.3, R4.1
/A5_SCL: P8.6, P10.3, P12.2 (PM), P16.2, P16.4, P17.4, R3.1
/CK: P3.5, P4.5, P6.11, U1.13 (CLK), U2.13 (CLK)
/D2: K4.1, P6.5, P18.1
/D3: K3.1, P6.6, P18.2
/D4: K2.1, P6.7, P18.3
/D5: K1.1, P6.8, P18.4
/D6: P6.9, P9.2, R5.2
/D7: P3.4, P4.4, P6.10, R2.1, U1.12 (LOAD), U2.12 (LOAD)
/D9: P3.3, P6.12, U1.1 (DIN), U2.1 (DIN)
/D10: P7.1, P19.1
/D11: P7.2, P19.2
/D12: P7.3, P19.3
/D13: P7.4, P19.4
/DOUT: P4.3, U1.24 (DOUT), U2.24 (DOUT)
/IS: R1.2, U1.18 (ISET), U2.18 (ISET)
/VCCRTC: P8.3, P11.1
GND: C1.1, C2.2, K1.2 (PM), K2.2 (PM), K3.2 (PM), K4.2 (PM), K5.2 (PM), K6.2 (PM), P3.2, P4.2, P7.11, P8.4, P9.4, P10.2, P11.2 (PM), P15.2, P15.4, P17.1, R2.2, R7.2, U1.4 (GND), U1.9 (GND), U2.4 (GND), U2.9 (GND)
unnamed: P8.1, P14.2 (PM)
unnamed: P8.2, P14.1
unnamed: Q1.2 (G), R6.2, R7.1
VCC: C1.2, C2.1, K5.1, P3.1, P4.1, P7.9, P8.8, P9.1, P15.1, P15.3, P17.2, R1.1, R3.2, R4.2, R5.1, R6.1, R8.1, U1.19 (VCC), U2.19 (VCC)

Board: 2 copper layers, 38 parts (2 on the bottom side), 44 nets, no tracks yet.

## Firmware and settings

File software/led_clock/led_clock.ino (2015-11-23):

/*
  ===================================
  Led Matrix Clock
  A word clock and whatever you want!
  https://github.com/issalig/lec-clock
  ===================================

  file: led_clock.ino
  description: led-clock
  date: 25/05/2014
  author: Ismael Salvador
*/

//includes
#include "config.h"

#include <avr/sleep.h> 

#include <ButtonJC.h>
#include <Time.h>
#include <TimeAlarms.h>

#include "DHT.h"
#include "LedControl.h"

#include <Wire.h>
#include "RTClib.h"

#include <Cmd.h>

#define DEBUG_SERIAL 0

//use eeprom for mask (saves ram space)
#define USE_EEPROM

//clock type
#define WORD_CLOCK   0
#define NUMBER_CLOCK 1

//common cathode or anode led matrix
#define USE_7219_C_CATHODE 0
#define USE_7219_C_ANODE   1

#define USE_RTC 1
#define USE_BUTTONS 1
#define USE_DHT11       1
#define USER_SOFT_I2C   1


enum {MODE_OFF, MODE_ON, MODE_HOUR, MODE_MINUTE};
enum {SET_PLUS};

// global variables
int cyear, cmonth, cday, chour, cminute, csecond; //time
double humidity, temperature, dew_point; //weather
int moon; //moon
long int refresh_delay = 60000; //refresh once a minute
int mode;
int intensity = 8;
long int last_refresh = 0;

#if (USE_RTC)
RTC_DS1307 rtc;
#else
RTC_Millis rtc;
#endif

DHT dht(DHT_PIN, DHT11);

LedControl lc = LedControl(9, 8, 7); //dataIn7219, clk7219, load7219, 4); //up to 4 devices

//Button button_mode = Button(BUTTON_MODE, PULLUP);
//Button button_set = Button(BUTTON_SET, PULLUP);
ButtonJC button_mode(BUTTON_MODE, true, true, 20);//, PULLUP, INVERT, DEBOUNCE_MS);
ButtonJC button_set(BUTTON_SET, true, true, 20);//, PULLUP, INVERT, DEBOUNCE_MS);

DateTime dnow;

//preparing the luggage
void setup() {

  Serial.begin(9600);
  cmd_help(0, NULL);

  if (USE_DHT11) {
    dht.begin();
  }

  init_matrix_pins();

  setup_time();
  setup_cmds();

  mode = MODE_ON;

  //read_time();
  //setTime(chour,cminute,csecond,cday,cmonth,cyear);
  //Alarm.timerRepeat(5, led_alarm);
  //Alarm.alarmRepeat(dowSaturday,8,30,30,WeeklyAlarm);  // 8:30:30 every Saturday
  weather_setup();
}

//let's go for a trip
void loop() {
  if (mode == MODE_ON) {
    if (1){ //if (millis() > (last_refresh + refresh_delay)) {
      last_refresh = millis();
      read_time();
      fill_matrix(0);   //clear screen
      if (!button_set.isPressed())
        draw_time();
    }
  }
  manage_buttons();
  cmdPoll();
  //print_debug_info();
  weather_update();
}

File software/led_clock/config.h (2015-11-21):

/*
  file: config.h
  description: settings
  date: 14/03/2015
  author: Ismael Salvador
*/

//pinout version
#define VERSION_0_4

#if defined(VERSION_0_2)
#define DHT      D6
#define BUTTON_0 A1
#define BUTTON_1 A2
#define BUTTON_2 A3
#define BUTTON_3 A4
//7219
#define LOAD_7219 D10
#define CLK_7219  D11
#define DIN_7219  D12
#endif

///////////////////////////
#if defined(VERSION_0_3)
#define DHT      D6
#define BUTTON_0 D2
#define BUTTON_1 D3
#define BUTTON_2 D4
#define BUTTON_3 D5
//7219
#define LOAD_7219 D7
#define CLK_7219  D8
#define DIN_7219  D9
#endif

///////////////////////////
#if defined(VERSION_0_4)
#define LDR     A2

#define BUTTON_0 2
#define BUTTON_1 4
#define BUTTON_MODE BUTTON_1
#define BUTTON_SET BUTTON_0

#define LED_R D3
#define LED_G D5
#define LED_B D6
//7219
#define DIN_7219 A0
#define LOAD_7219 7
#define CLK_7219  8
//dht
#define DHT_PIN 6
//nokia
#define RST_NK 7
#define CLK_NK 8
#define LIGHT_NKD9
#define CE_NK 10
#define DIN_NK 11
#define CE_NK 10
//ir
#define IR1838 12

//dht
#define DHT_TYPE         DHT11 
#define DHT_PIN 6


#endif

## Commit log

2014-07-13 dir strcuture
    [ledmatrix.scad]
2014-07-13 arduino scripts
2014-12-14 Hardware folder
    Kicad files
    [.kicad_pcb.kicad_pcb, matrix7219.sch, matrix7219_5cm - copia.kicad_pcb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]
2015-03-14 cleaning
    cleaning files
    [matrix7219_5cm-B_Cu.gbl, matrix7219_5cm-B_Mask.gbs, matrix7219_5cm-B_SilkS.gbo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]
2015-11-21 multiple 7219 devices
2015-11-21 power saving
2015-11-29 simple pressure functions
